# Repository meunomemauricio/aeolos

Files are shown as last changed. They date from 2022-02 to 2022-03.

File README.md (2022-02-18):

# Aeolus

Arduino PWM Fan Controller.

## Uploading Firmware

This projects use Platform IO. When building or uploading the firmware, it's
important to specify the build environment. This will set the proper
`MODULE_ID` value depending on the expected fan direction.

    pio run -e exhaust -t upload
    pio run -e intake -t upload

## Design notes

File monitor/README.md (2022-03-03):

# Aeolos Monitor

Simple GUI to monitor the Fan Speed in real time.

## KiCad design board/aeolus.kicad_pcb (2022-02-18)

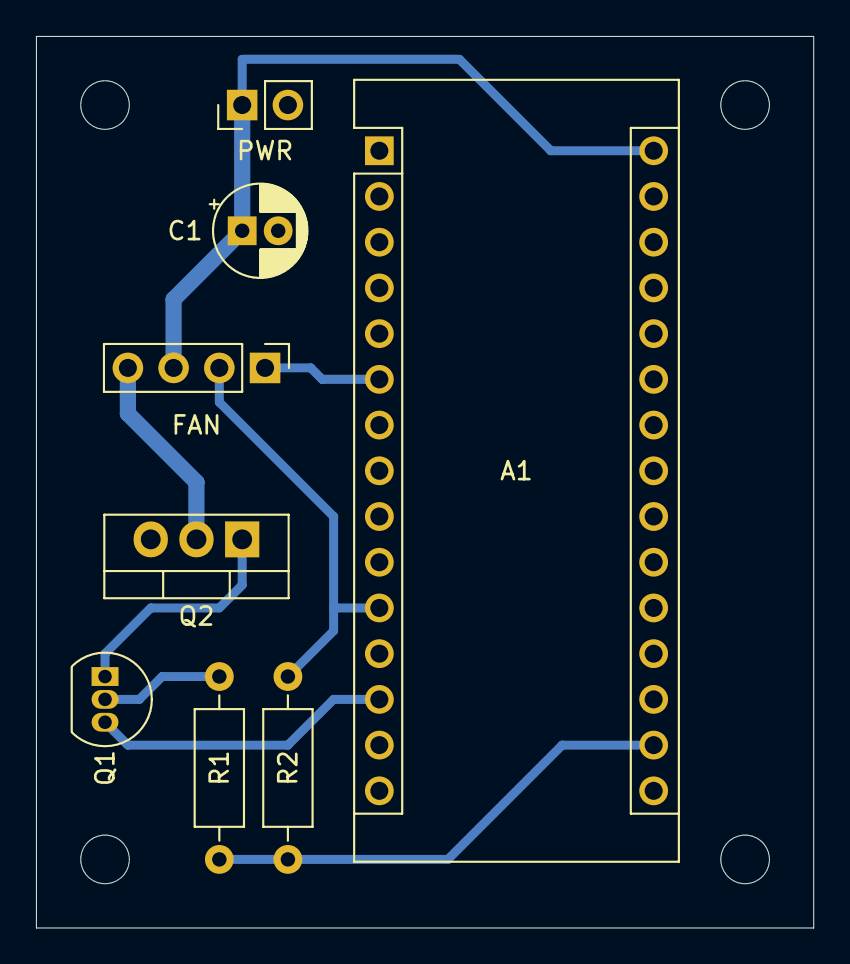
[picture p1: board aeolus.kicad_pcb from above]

Board: 2 copper layers, 43.2 x 49.5 mm, 8 parts (0 on the bottom side), 9 nets.

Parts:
A1: Arduino_Nano_v2.x; Arduino_Nano
C1: 1uF; CP_Radial_D5.0mm_P2.00mm
FAN: Conn_01x04_Male; PinHeader_1x04_P2.54mm_Vertical
PWR: Conn_01x02_Male; PinHeader_1x02_P2.54mm_Vertical
Q1: BC549; TO-92_Inline
Q2: IRF540N; TO-220-3_Vertical
R1, R2: 10k; R_Axial_DIN0207_L6.3mm_D2.5mm_P10.16mm_Horizontal

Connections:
+3V3: A1.17, R1.1, R2.1
+12V: A1.30, C1.1, FAN.3, PWR.1
/FAN_GND: FAN.4, Q2.2
/PWM: A1.6, FAN.1
/TACH: A1.11, FAN.2, R2.2
GND: A1.29, C1.2, PWR.2, Q2.3
unnamed: A1.13, Q1.3
unnamed: Q1.1, Q2.1
unnamed: Q1.2, R1.2

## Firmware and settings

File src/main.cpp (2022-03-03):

/** PID Fan Controller */

#include <AceButton.h>
#include <Arduino.h>
#include <PID_v1.h>

using namespace ace_button;

/** Defines */
#define BAUD_RATE 115200
#define SAMPLE_TIME 22  // ms

// Pins
#define BTN_DECREASE 5
#define BTN_INCREASE 6

#define FAN_CONTROL 3
#define FAN_TACH 8
#define FAN_POWER 10

// TODO: Documment value choice
#define OCRA_VALUE 88

#define MIN_RPM 550
#define MAX_RPM 1750

#define RPN_STEP_N 9  // Number of desired steps, minus 1

#define MIN_ACTUATOR 0
#define MAX_ACTUATOR OCRA_VALUE

/** Global Variables */
// Main Loop Timing
unsigned long previous_millis = 0;

// Fan Variables
bool power_status = false;

const double rpm_step = (MAX_RPM - MIN_RPM) / (double)RPN_STEP_N;
// How many speed steps are active. -1 is turned off;
int8_t fan_steps = -1;

// Buttons
ButtonConfig btn_cfg;
AceButton btn_inc(&btn_cfg, BTN_INCREASE);
AceButton btn_dec(&btn_cfg, BTN_DECREASE);

void handle_btn_event(AceButton*, uint8_t, uint8_t);  // Fwr Ref

// Sensor - Declared as volatile since they can change in interrupts
volatile double rpm_value = 0.0;

// Controller
double setpoint = 0.0;
double output = 0.0;
double kp = 0.15, ki = 0.22, kd = 0.005;

// TODO: Figure out how to solve the volatile warning
PID pid_cntlr(&rpm_value, &output, &setpoint, kp, ki, kd, DIRECT);

// Setup Functions

/** Setup Fan and Tachometer pins. */
void setup_pins() {
  pinMode(BTN_DECREASE, INPUT_PULLUP);
  pinMode(BTN_INCREASE, INPUT_PULLUP);

  pinMode(FAN_POWER, OUTPUT);
  digitalWrite(FAN_POWER, LOW);  // Make sure the FAN is off when booting

  pinMode(FAN_CONTROL, OUTPUT);
  pinMode(FAN_TACH, INPUT);
  pinMode(LED_BUILTIN, OUTPUT);
}

/** Setup the PWM to control the fans.

   TOP is set as OCRA in order to achieve 22.5 KHz:
             Clk              16MHz
    OCRA = -------- - 1 = ------------- - 1 = 87,88... ~= 88
            Ps * f         8 * 22.5KHz
 */
void setup_pwm() {
  // Timer 2 - Fast PWM - Non Inverting -
  TCCR2A = bit(COM2B1) | bit(WGM21) | bit(WGM20);
  // TOP OCRA - Clk/8
  TCCR2B = bit(WGM22) | bit(CS21);
  OCR2A = OCRA_VALUE;
  OCR2B = 0;
}

/** Setup Timer 1 for Input Capture.
 *
 * Used to capture transitions from the Fan Speed Sensor.
 */
void setup_input_capture() {
  TCCR1A = 0;
  // Input Capture Noise Canceler + Rising Edge + Clk/64
  TCCR1B = bit(ICNC1) | bit(ICES1) | bit(CS11) | bit(CS10);
  TCCR1C = 0;

  // Clear ready and enable interrupt
  TIFR1 = bit(ICF1);
  TIMSK1 = bit(ICIE1);
}

/** Setup the PID Controller. */
void setup_controller() {
  pid_cntlr.SetMode(AUTOMATIC);
  pid_cntlr.SetControllerDirection(DIRECT);
  pid_cntlr.SetOutputLimits(MIN_ACTUATOR, MAX_ACTUATOR);
  pid_cntlr.SetSampleTime(SAMPLE_TIME);
}

/** Main Setup function */
void setup() {
  Serial.begin(BAUD_RATE);
  setup_pins();
  setup_pwm();
  setup_input_capture();
  setup_controller();
  sei();

  btn_cfg.setEventHandler(handle_btn_event);
}

// Interrupt Routines

/** Convert to RPM.
 *
 * Convert the values from the Input Compare to an RPM value.
 * TODO: Write formula;
 * TODO: Optimize?
 * TODO: Is this even accurate?
 */
double convert_to_rpm(unsigned int duration) {
  return 7500000.0 / (double)duration;
}

/** Interrupt function for Capture Events. */
ISR(TIMER1_CAPT_vect) {
  rpm_value = convert_to_rpm(ICR1);
  // Reset the Counter and clear the interrupt
  TCNT1 = 0;
  TIFR1 |= bit(ICF1);
}

// FAN Control Functions

/** Turn the Fan Power OFF. */
void fan_off() {
  digitalWrite(FAN_POWER, LOW);
  bitClear(TIMSK1, ICIE1);    // Disable sensor interrupt
  pid_cntlr.SetMode(MANUAL);  // Disable controller while powered off
  setpoint = 0;
  OCR2B = 0;
  rpm_value = 0;
  power_status = false;
}

/** Turn the Fan Power ON.
 *
 * The Setpoint is reset to MIN_RPM when turning it on.
 */
void fan_on() {
  bitSet(TIMSK1, ICIE1);  // Reenable sensor interrupt
  digitalWrite(FAN_POWER, HIGH);
  setpoint = MIN_RPM;
  pid_cntlr.SetMode(AUTOMATIC);  // Reenable the controller
  power_status = true;
}

/** Button Event Handler.  */
void handle_btn_event(AceButton* btn, uint8_t event_type, uint8_t) {
  if (event_type != AceButton::kEventReleased) {
    return;
  }

  if (btn->getPin() == BTN_DECREASE) {
    fan_steps--;
  } else {
    fan_steps++;
  }

  fan_steps = constrain(fan_steps, -1, RPN_STEP_N);

  if (power_status && fan_steps < 0) {
    fan_off();
  } else if (!power_status && fan_steps >= 0) {
    fan_on();
  } else if (fan_steps >= 0) {
    setpoint = MIN_RPM + (fan_steps * rpm_step);
  }
}

// Main Loop Functions

/** Check the buttons, triggering events if necessary. */
void check_buttons(void) {
  btn_dec.check();
  btn_inc.check();
}

/** Print current speed and setpoint to the serial. */
void print_speed(void) {
  Serial.print(rpm_value);
  Serial.print(",");
  Serial.println(setpoint);
}

/** Compute the PID Controller Logic.
 *
 * Function is rate limited by the SAMPLE_TIME;
 */
void process_controller(void) {
  unsigned long current_millis = millis();
  if (current_millis - previous_millis >= SAMPLE_TIME) {
    previous_millis = current_millis;
    print_speed();  // TODO: Enable/Disable via build settings

    if (power_status) {
      pid_cntlr.Compute();
      OCR2B = output;
    }
  }
}

/** Main Loop */
void loop() {
  check_buttons();
  process_controller();
}

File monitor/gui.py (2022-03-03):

"""GUI for monitoring fan speed."""

import numpy as np
import os
import serial
import sys

from PyQt5 import uic
from PyQt5.QtCore import QTimer, Qt
from PyQt5.QtWidgets import QApplication, QMainWindow
from pyqtgraph import mkPen


class FanControllerMainWindow(QMainWindow):
    """Application Main window."""

    UPDATE_PERIOD = 22
    WINDOW_SIZE = 660
    PLOT_RANGE = (0, 2000)

    # TODO: Configure port and baud via GUI
    PORT = "/dev/ttyUSB0"
    BAUD_RATE = 115200
    TIMEOUT = 1.0

    def __init__(self, app):
        super(FanControllerMainWindow, self).__init__()

        self.app = app
        self.serial = serial.Serial(
            port=None,
            baudrate=self.BAUD_RATE,
            timeout=self.TIMEOUT,
        )
        # Not defined via constructor so we can open connection later
        self.serial.port = self.PORT

        # Load UI and Set it up
        ui_file = os.path.join(os.path.dirname(__file__), "main_window.ui")
        uic.loadUi(ui_file, self)
        self._initial_button_status()
        self._connect_signals()
        self._set_timer()
        self._setup_plot()

    def _initial_button_status(self):
        """Disable/Enable based on initial status."""
        self.connectButton.setEnabled(True)
        self.disconnectButton.setEnabled(False)

    def _connect_signals(self):
        """Connect the signals to the UI elements."""
        self.actionQuit.triggered.connect(self.close)

        self.connectButton.clicked.connect(self.connect)
        self.disconnectButton.clicked.connect(self.disconnect)

        self.app.aboutToQuit.connect(self.disconnect)

    def _set_timer(self):
        self.timer = QTimer()
        self.timer.timeout.connect(self.update_data)
        # TODO: Start/Stop timer with connect/disconnect
        self.timer.start(self.UPDATE_PERIOD)

    def _setup_plot(self):
        self.previous_line = None

        self.speed_data = np.full(self.WINDOW_SIZE, np.nan)
        self.setpoint_data = np.full(self.WINDOW_SIZE, np.nan)

        self.plot_item = self.graphicsView.getPlotItem()
        self.plot_item.setYRange(*self.PLOT_RANGE)
        self.plot_item.setMouseEnabled(False, False)

        self.speed_curve = self.graphicsView.plot(self.speed_data)
        self.setpoint_curve = self.graphicsView.plot(self.setpoint_data)

    def _toggle_buttons(self, connected):
        """Toggle UI buttons in accordance with Connection status."""
        self.connectButton.setEnabled(not connected)
        self.disconnectButton.setEnabled(connected)

    def connect(self):
        """Connect and Sync with the Controller."""
        self.serial.open()
        self._toggle_buttons(connected=True)

    def disconnect(self):
        """Disconnect from the controller."""
        self.serial.close()
        self._toggle_buttons(connected=False)

    def _add_data_points(self, speed: float, setpoint: float) -> None:
        """Add new data points to graph, making sure to rotate data as necessary."""
        self.speed_data[:-1] = self.speed_data[1:]
        self.speed_data[-1] = speed
        self.speed_curve.setData(self.speed_data, connect="finite")

        self.setpoint_data[:-1] = self.setpoint_data[1:]
        self.setpoint_data[-1] = setpoint
        self.setpoint_curve.setData(
            self.setpoint_data,
            connect="finite",
            pen=mkPen("y", style=Qt.DashLine),
        )

    def _update_labels(self, speed: float, setpoint: float) -> None:
        """Display the current Speed and Setpoint in their respective labels."""
        self.rpmLabel.setText(speed.decode("utf-8"))
        self.spLabel.setText(setpoint.decode("utf-8"))

    # TODO: Move to another thread?
    def update_data(self):
        if not self.serial.is_open:
            return

        while self.serial.in_waiting:
            line = self.serial.readline()
            speed, setpoint = line.strip().split(b',', maxsplit=1)
            self._add_data_points(speed=float(speed), setpoint=float(setpoint))
            self._update_labels(speed=speed, setpoint=setpoint)


def run_gui():
    app = QApplication(sys.argv)
    window = FanControllerMainWindow(app)
    window.show()
    sys.exit(app.exec_())

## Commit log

2022-02-18 Project basic Setup (#1)
    * Update README
    * Extract from other repository
    * Rename board and create SCAD file
    [aeolus.kicad_pcb, aeolus.sch]
2022-03-03 Button Interface and Serial Monitor app (#2)
    * Remove old communication
    * Add AceButton library
    * Specify .clang-format
    * Revert back to cpp file
    * Add simple button logic
    * Adjust SP with buttons
    * Small adjustments
    * Create monitor GUI
    * Remove unused code
    * Finish monitor serial logic
    * Start setpoint on 0
    * Adjust controller parameters
    * Review adjustments
    [gui.py, main.cpp]
